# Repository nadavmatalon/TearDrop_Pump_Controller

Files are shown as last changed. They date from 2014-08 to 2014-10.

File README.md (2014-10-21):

#TearDrop Pump Controller

##Table of Contents

* [Screenshots](#screenshots)
* [About the Project](#about-the-project)
* [About the Pump Controller](#about-the-pump-controller)
* [License](#license)

##Screenshots

<table>
	<tr>
		<td align="center" width=25% >
			<a href="https://raw.githubusercontent.com/nadavmatalon/TearDrop_Pump_Controller/master/images/TDPC_Arduino.jpg">
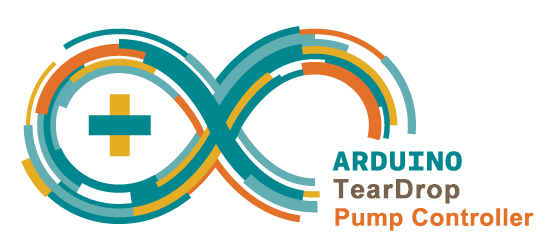
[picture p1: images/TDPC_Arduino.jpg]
				
			</a>
		</td>
		<td align="center" width=25% >
			<a href="https://raw.githubusercontent.com/nadavmatalon/TearDrop_Pump_Controller/master/images/TDPC_PCB.jpg">
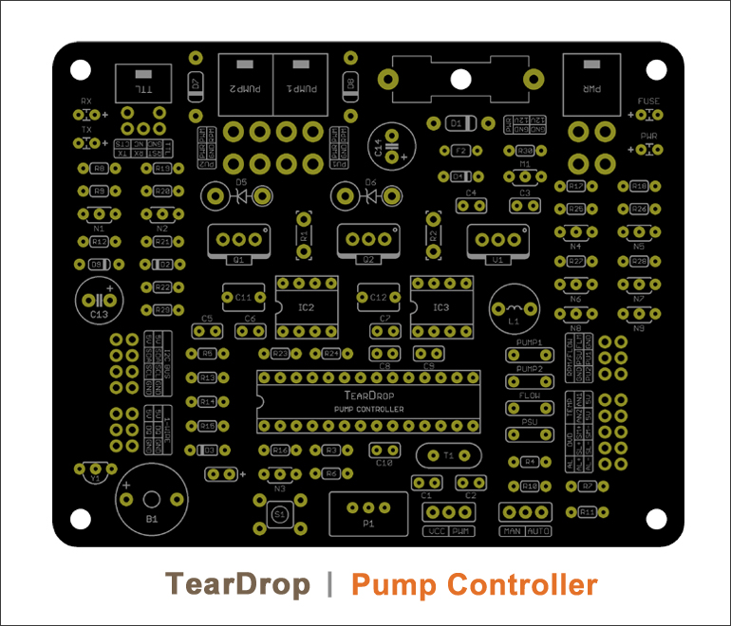
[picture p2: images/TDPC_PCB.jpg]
				
			</a>
		</td>
		<td align="center" width=25% >
			<a href="https://raw.githubusercontent.com/nadavmatalon/TearDrop_Pump_Controller/master/images/TearDrop_1.jpg">
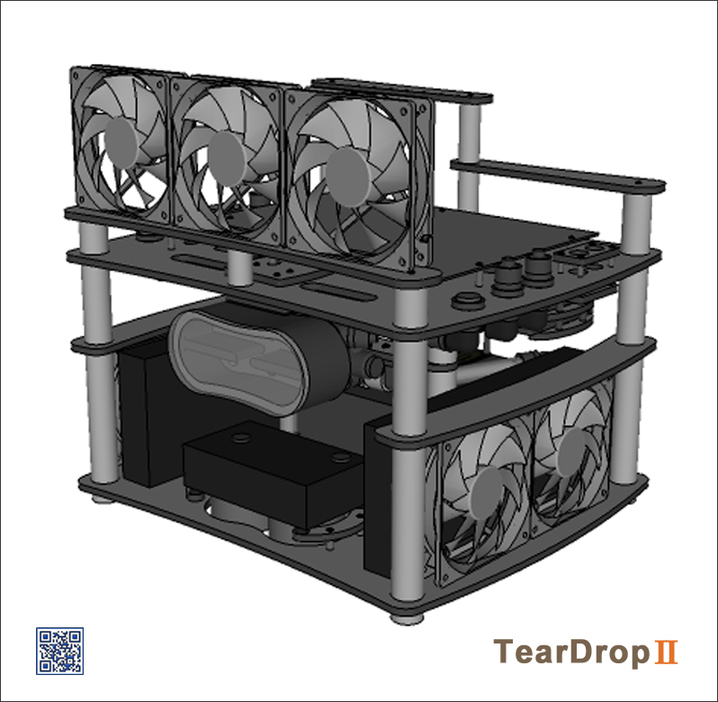
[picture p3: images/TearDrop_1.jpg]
				
			</a>
		</td>
		<td align="center" width=25% >
			<a href="https://raw.githubusercontent.com/nadavmatalon/TearDrop_Pump_Controller/master/images/TearDrop_2.jpg">
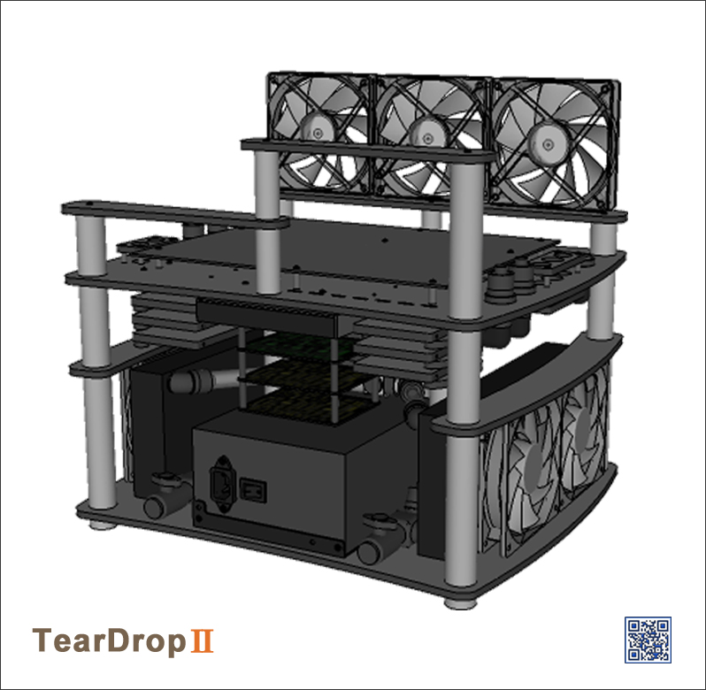
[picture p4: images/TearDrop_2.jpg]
				
			</a>
		</td>
	</tr>
</table>

##About the Project
 
__TearDrop__ is a custom, open-frame, water-cooled scratch build I’ve been 
working on as part of the SnowCrash initiative.

The __SnowCrash__ initiative aims at designing and building end-to-end customized 
personal computers, addressing unique functional requirements – from developing 
the software control applications, to hardware configuration and case modding. 
As part of the initiative's research phase, the TearDrop customized computer 
prototype has been developed.

The underlying motivation for this specifc project was to research, design, 
prototype and finally create everything that's needed for a fully-customized 
desktop computer.

In this context, I’ve learned to program micro-controllers, design, prototype 
and build electronic circuit boards, make CNC cutting templates, interface with 
various kinds of hardware, write front-end applications, and lots more.

This project also helped me to become proficient in multiple software tools, including: 
[Google Sketchup](http://www.sketchup.com/), 
[Arduino IDE](http://www.arduino.cc/), [Processing 2.0](http://processing.org/), 
[CadSoft Eagle](http://www.cadsoftusa.com/download-eagle/freeware/), 
and [Inkscape](http://www.inkscape.org/en/).
 
The __project-log__ of this build (which I haven't had time to update recently, but 
does include loads of cool pictures :-), can be found 
at [bit-tech](http://forums.bit-tech.net/showthread.php?t=234218).

##About the Pump Controller

This repo contains the custom Pump Controller I’ve designed and built 
to control __TearDrop__’s dual-pump cooling system.

This repo contains the following files:

* __arduino__

    The source code for the ATmega328P that runs the Pump Controller 

    The file can can be directly accessed by clicking this link:

    * [Pump Controller](arduino/TearDrop_Pump_Controller/TearDrop_Pump_Controller.ino)

	The source code requires three supporting open-source [Arduino](http://www.arduino.cc/) libraries.

	For convenience, these libraries are inlcuded here in their own sub-folder.

	Credit goes to:

	[PinChangeInt](http://playground.arduino.cc/Main/PinChangeInt)

	[OneWire](https://github.com/ntruchsess/arduino-OneWire/tree/master)

	[WSWire](https://github.com/steamfire/WSWireLib)

* __eagle__

    This folder contains the complete hardware schematics & PCB design of the Pump Controller.

    __Please do not click on the files in this sub-folder as they are in foramts that 
    are incompatible with Github's hosting server__.

    However, the files can be downloaded and run as usual with [CadSoft](http://www.cadsoftusa.com/?language=en)'s 
    free version of [Eagle](http://www.cadsoftusa.com/download-eagle/freeware/).

* __parts__

	A speadsheet with all information about the parts used for building the Pump Controller.

	__The file in this sub-folder is also in a foramt that's incompatible with Github's hosting server__.

    However, it can be downloaded and run as usual with any spreadsheet editing software.

##  License

<p>Released under the <a href="http://www.opensource.org/licenses/MIT">MIT license</a>.</p>

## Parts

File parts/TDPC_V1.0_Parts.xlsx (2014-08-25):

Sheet: Sheet1
TEARDROP
NAME | TYPE | VALUE / RATING | PACKAGE / DIMENSIONS | NUMBER | MANUFACTURER | MPN | SOURCE | DATASHEET | ACTUAL | ACTUAL | MINIMUM | ACTUAL | MINIMUM | MINIMUM | ACTUAL | MINIMUM | MINIMUM | MINIMUM
 |  |  | (mm) | OF |  |  |  | LEAD | LEAD | LEAD | HOLE | HOLE | ANNULAR RING | PAD | PAD | HOLE | PAD | PAD
 |  |  |  | UNITS |  |  |  | DIAMETER | DIAMETER | DIAMETER | DIAMETER | DIAMETER | SIZE | DIAMETER | DIAMETER | DIAMETER | DIAMETER | DIAMETER
 |  |  |  |  |  |  |  | (mm) | (wide side) | (narrow side) | (mm) | (mm) | (mm) | (mm) | (mm) | CHECK | CHECK (1) | CHECK (2)
PWR, PUMP1, PUMP2 | 4P (2x2) POWER SOCKET (FEMALE) | 10A | KK, HORIZONTAL | 3 | MOLEX | MB-4PIN-SB | modDIY (MB-4PIN-SB) | ─ | 1.2 | 1.2 | 1.454 | 1.75 | 0.2 | 2.25 | 3.3 | 1.35 | 0.15 | 1.0
PWR, PUMP1, PUMP2 | 4P (2x2) POWER CONNECTOR (MALE) | 10A | KK, HORIZONTAL | 3 | MOLEX | MB-4PIN-F | modDIY (MB-4PIN-F) | ─ | ─ | ─ | ─ | ─ | ─ | ─ | ─ | ─ | ─ | ─
USB-TTL | 6P (2x3) SOCKET (FEMALE) | RIGHT ANGLE, 2.54 |  | 1 | MOLEX | 90130-3206 | eBay (350819406809) |  |  |  | 0.254 |  | 0.2 | 0.5 | 1.7 | -0.4 | 1.7 | 1.2
USB-TTL | 6P (2x3) CONNECTOR (MALE) | ─ | ─ | 1 | MOLEX | 90142-0006 | eBay (111189947049) | ─ | ─ | ─ | ─ | ─ | ─ | ─ | ─ | ─ | ─ | ─
USB-TTL | CONNECTOR CRIMPS | ─ | ─ | 6 | MOLEX | 90119-2120 | eBay (111189965216) | ─ | ─ | ─ | ─ | ─ | ─ | ─ | ─ | ─ | ─ | ─
I/O | RIGHT-ANGLE MALE HEADERS | 2x3, 2x4, 2x5 | DUAL ROW, 2.54 | 3 | UNKOWN | UNKNOWN | eBay (321027689319) | ─ | 0.7 | 0.7 | 0.954 | 1.1 | 0.2 | 1.6 | 2.0 | 0.7 | 0.02 | 0.4
IC1 | ATMEGA328P | ─ | DIP-28 | 1 | ATMEL | ATMEGA328P | eBay(281158389853) | ─ | ─ | ─ | ─ | ─ | ─ | ─ | ─ | ─ | ─ | ─
(IC1) | DIL-28 SOCKET | ─ | 35.6x10, 2.54 | 1 | UNKNOWN | UNKNOWN | eBay(181062492231) | 0.5 | 0.5 | 0.5 | 0.754 | 0.7 | 0.2 | 1.2 | 1.8 | 0.3 | 0.54 | 0.6
IC2, IC3 | MIC4421 (MOFSET DRIVER) | 9A | DIP-8 | 2 | MICREL | MIC4421YN | Mouser (998-MIC4421YN) | ─ | ─ | ─ | ─ | ─ | ─ | ─ | ─ | ─ | ─ | ─
[IC2, IC3] | [MCP1406 (IMPROVEMENT OF TC4429)] | [6A] | [DIP-8] | [2] | MICROCHIP | MCP1406-E/P | Mouser (579-MCP1406-E/P) | ─ | ─ | ─ | ─ | ─ | ─ | ─ | ─ | ─ | ─ | ─
(IC2, IC3) | DIL-8 SOCKET | 3A | 10.1x10.2 | 2 | MILL-MAX | 110-44-308-41-001000 | Mouser (575-144308) | 0.5 | 0.5 | 0.5 | 0.754 | 0.7 | 0.2 | 1.2 | 1.8 | 0.3 | 0.54 | 0.6
 |  |  |  |  |  |  | Farnell (1351428)
[IC2, IC3] | [DIL-8 SOCKET] | [3A] | [10x10] | [2] | TE Connectivity / AMP | 808-AG11D-ES-LF | Mouser (571-4-1571552-3) | 0.5 | 0.5 | 0.5 | 0.754 | 0.7 | 0.2 | 1.2 | 1.8 | 0.3 | 0.54 | 0.6
Y1 | DS18B20 (DIGITAL TEMPERATURE SENSOR) | ─ | TO-92 | 1 | DALLAS | DS18B20 | eBay (301049284143) | 0.5 | 0.5 | 0.5 | 0.754 | 0.7 | 0.2 | 1.2 | 1.8 | 0.3 | 0.54 | 0.6
V1 | LM7805 (VOLTAGE REGULATOR) | 5V | TO-220 | 1 | FAIRCHILD | LM7805ACT | Mouser (512-LM7805ACT) | Narrow: 0.64 | 0.86 | 0.45 | 1.114 | 1.1 | 0.2 | 1.6 | 2.1 | 0.7 | 0.12 | 0.5
 |  |  |  |  |  |  |  | Wide: 1.52
[V1] | [LM7805 (VOLTAGE REGULATOR)] | [5V] | [TO-220] | [1] | ON SEMICONDUCTOR | MC33269T-5.0G | Mouser (863-MC33269T-5.0G) | Narrow: 0.64 | 0.86 | 0.45 | 1.114 | 1.2 | 0.2 | 1.7 | 2.1 | 0.8 | -0.06 | 0.4
 |  |  |  |  |  |  |  | Wide: 1.52
F1 | FAST-BLOW GLASS FUSE | 6.3A | 8x20MM | 1 | UKNOWN | UNKWNON | UNKNOWN | ─ | ─ | ─ | ─ | ─ | ─ | ─ | ─ | ─ | ─ | ─
(F1) | FUSE HOLDER | 10A / 250V | 22.5x9.6mm | 1 | Schurter | 0031.8211 | Mouser (693-0031.8201) | 1.3 | 1.2 | 0.46 | 1.454 | 1.45 | 0.2 | 1.95 | 3.3 | 1.05 | 0.69 | 1.3
F2 | PTC (RESETTABLE FUSE) | 0.5A / 60V | 6.8x1.9, 5.1 | 1 | BOURNS | MF-R050 | Mouser (652-MFR050) | 0.5 | 0.55 | 0.5 | 0.804 | 0.7 | 0.2 | 1.2 | 1.6 | 0.3 | 0.34 | 0.4
L1 | INDUCTOR | 10uH / 4A7 | 8.7x12.3, 5.08 | 1 | Wurth Electronics | 7447452100 | Mouser (710-7447452100) | 0.7 | 0.65 | 0.7 | 0.904 | 0.9 | 0.2 | 1.4 | 2.1 | 0.5 | 0.48 | 0.7
C1, C2 | CAPACITOR (MLCC) | 22pF / 50V | 3.8x2, 2.6 | 2 | AVX | SR155A220JAR | Mouser (581-SR155A220JAR) | 0.5 | 0.5 | 0.5 | 0.754 | 0.7 | 0.2 | 1.2 | 1.7 | 0.3 | 0.44 | 0.5
C3 | CAPACITOR (MLCC) | 470nF / 25V | 4x2.5, 3 | 1 | TDK | FK18X7R1E474K | Mouser (810-FK18X7R1E474K) | 0.5 | 0.55 | 0.55 | 0.804 | 0.7 | 0.2 | 1.2 | 1.7 | 0.3 | 0.44 | 0.5
C4 - C10 | CAPACITOR (MLCC) | 100nF / 100V | 4.3x2.9, 2.6 | 7 | NOT KNOWN | NOT KNOWN | eBay (290933035294) | 0.5 | 0.5 | 0.5 | 0.754 | 0.7 | 0.2 | 1.2 | 1.7 | 0.3 | 0.44 | 0.5
[C4 - C10] | [CAPACITOR (MLCC)] | [100nF / 25V] | [4x2.5, 3] | [7] | [TDK] | [FK18X7R1E104K] | [Mouser (810-FK18X7R1E104K)] | 0.5 | 0.5 | 0.5 | 0.754 | 0.7 | 0.2 | 1.2 | 1.8 | 0.3 | 0.54 | 0.6
C11, C12 | WIMA CAPACITOR (5%) | 2.2uF / 50V | 5x7.2, 5.2 | 2 | WIMA | MKS2B042201F00JSSD | Mouser (505-MKS22.2/50/5) | 0.5 | 0.5 | 0.5 | 0.754 | 0.7 | 0.2 | 1.2 | 1.8 | 0.3 | 0.54 | 0.6
[C11, C12] | [WIMA CAPACITOR (10%)] | [2.2uF / 50V] | [5x7.2, 5] | [2] | [WIMA] | [MKS2B042201F00KSSD] | [Mouser (505-MKS22.2/50/10 )] |  |  |  | 0.254 |  |  | 0.1 |  | -0.4 | 0 | -0.5
[C11, C12] | [WIMA CAPACITOR (10%)] | [4.7uF / 50V] | [7.2x7.2, 5] | [2] | [WIMA] | [MKS2B044701K00KSSD] | [Mouser (505-MKS2-4.7/50/10)] |  |  |  | 0.254 |  |  | 0.1 |  | -0.4 | 0 | -0.5
[C11, C12] | [WIMA CAPACITOR (5%)] | [1uF / 63V] | [5x7.2, 5] | [2] | WIMA | [MKS2C041001F00JS] | [Mouser (505-MKS21.0/63/5)] |  |  |  | 0.254 |  |  | 0.1 |  | -0.4 | 0 | -0.5
[C11, C12] | [WIMA CAPACITOR (5%)] | [1uF / 63V] | [5x7.2, 5] | [2] | [WIMA] | [MKS2-1/63/5T] | [Mouser (505-MKS21/63/5T)] |  |  |  | 0.254 |  |  | 0.1 |  | -0.4 | 0 | -0.5
C13 | CAPACITOR (ELECTROLYTIC) | 100uF / 50V | 8x12.2, 5 | 1 | PANASONIC | EEU-FR1H101B | Mouser (667-EEU-FR1H101B) | 0.6 | 0.6 | 0.6 | 0.854 | 0.9 | 0.2 | 1.4 | 2.1 | 0.5 | 0.48 | 0.7
C14 | CAPACITOR (ELECTROLITIC) | 470uF / 35V | 8.3x21.6, 3.5 | 1 | PANASONIC | EEU-FR1V471L | Mouser 667-EEU-FR1V471L | 0.6 | 0.6 | 0.6 | 0.854 | 0.9 | 0.2 | 1.4 | 2.1 | 0.5 | 0.48 | 0.7
Q1, Q2 | IRF5210 (P-CHANNEL MOSFET) | 30V / 50A | TO-220 | 2 | INTERNATIONAL RECIFIER | IRF5210PBF | Mouser (942-IRF5210PBF) | Narrow: 0.64 | 0.86 | 0.45 | 1.114 | 1.1 | 0.2 | 1.6 | 2.1 | 0.7 | 0.12 | 0.5
 |  |  |  |  |  |  |  | Wide: 1.52
(Q1, Q2, V1) | MOSFET / VOLTAGE REGULATOR HEATSINK (TO-220) | 32C/W | 6.35x13.3 | 3 | AAVID THERMALLOY | 577002B00000G | Mouser (532-577002B00) | ─ | ─ | ─ | ─ | ─ | ─ | ─ | ─ | ─ | ─ | ─
N1 - N9 | ZVN2106A (N-CHANNEL MOSFET) | 0.2A / 60V | TO-92 | 9 | FAIRCHILD | ZVN2106A | Mouser (522-ZVN2106A) | 0.5 | 0.5 | 0.5 | 0.754 | 0.7 | 0.2 | 1.2 | 1.8 | 0.3 | 0.54 | 0.6
M1 | ZVP2106A (P-CHANNEL MOSFET) | 0.2A / 60V | 2.3x4.6 | 1 | DIODES INC | ZVP2106A | Mouser (522-ZVP2106A) | 0.5 | 0.5 | 0.5 | 0.754 | 0.7 | 0.2 | 1.2 | 1.8 | 0.3 | 0.54 | 0.6
D1 | 1N4007 (POWER DIODE) | 1000V / 1A | DO-41 (5x2.6) | 1 | FAIRCHILD SEMICONDUCTOR | 1N4007 | Farnell (1467514) | 0.87 | 0.8 | 0.8 | 1.054 | 0.9 | 0.2 | 1.4 | 2.2 | 0.5 | 0.58 | 0.8
D2 - D4 | 1N4148 (SIGNAL DIODE) | 100V / 200mA | DO-35 (3.2x1.6) | 3 | FAIRCHILD SEMICONDUCTORS | 1N4148 | Mouser (512-1N4148) | 0.56 | 0.5 | 0.5 | 0.754 | 0.7 | 0.2 | 1.2 | 1.8 | 0.3 | 0.54 | 0.6
D5, D6 | ICTE12 (TVS DIODE) | 12V / 1.5KW / UD | 9x5.2 | 2 | VISHAY | ICTE12-E3/51 | Mouser (625-ICTE12-E3/51) | 1.1 | 1.1 | 1.1 | 1.354 | 1.25 | 0.2 | 1.75 | 2.6 | 0.85 | 0.35 | 0.9
D7, D8 | UF4004 (PROTECTION DIODE) | 40V / 30A | DO-41 (5x2.6) | 2 | VISHAY | UF4004-E3/54 | Mouser (625-UF4004-E3) | 0.8 | 0.8 | 0.8 | 1.054 | 0.9 | 0.2 | 1.4 | 2.2 | 0.5 | 0.58 | 0.8
D9 | BZX79-B/C5V1 (ZENER DIODE) | 5V1 / 0.5W | DO-35 (3.6x1.6) | 1 | VISHAY | BZX55B5V1-TAP | Mouser (78-BZX55B5V1-TAP) | 0.5 | 0.5 | 0.5 | 0.754 | 0.7 | 0.2 | 1.2 | 1.8 | 0.3 | 0.54 | 0.6
T1 | CRYSTAL | 16Mhz | 10.8x4.4 | 1 | ABRACON | ABL-16.000MHZ-B2 | Mouser (815-ABL-16-B2) | 0.5 | 0.45 | 0.45 | 0.704 | 0.7 | 0.2 | 1.2 | 1.8 | 0.3 | 0.54 | 0.6
P1 | POTENTIOMETER (SINGL TURN) | 10K | 12.7x7.6 | 1 | VISHAY SPECTROL | 249FGJSPXB25103KA | Farnell (9609342) | 0.5 | 0.5 | 0.4 | 0.754 | 0.7 | 0.2 | 1.2 | 1.8 | 0.3 | 0.54 | 0.6
(P1) | POTENTIOMETER KNOB | ─ | 9.4x14 (Inner: 6mm) | 1 | UNKNOWN | UNKNOWN | eBay (310496284128) | ─ | ─ | ─ | ─ | ─ | ─ | ─ | ─ | ─ | ─ | ─
R1, R2 | RESISTOR | 100R / 15W | TO-126 (8.1x2.8) | 3 | CADDOCK | MP915-100-1% | Farnell (1612032) | 0.86 | 0.8 | 0.6 | 1.054 | 1.1 | 0.2 | 1.6 | 2.3 | 0.7 | 0.32 | 0.7
 |  |  |  |  |  |  | Mouser (684-MP915-100)
R3 - R4 | RESISTOR | 470R / 0.5W | 3.15x1.6 | 2 | VISHAY | SFR16S0004700JA500 | Farnell (9476059) | 0.5 | 0.46 | 0.46 | 0.714 | 0.7 | 0.2 | 1.2 | 1.8 | 0.3 | 0.54 | 0.6
R5 - R7 | RESISTOR | 560R / 0.5W | 3.15x1.6 | 3 | VISHAY | SFR16S0005600JA500 | Farnell (9476113) | 0.5 | 0.46 | 0.46 | 0.714 | 0.7 | 0.2 | 1.2 | 1.8 | 0.3 | 0.54 | 0.6
R8 - R11 | RESISTOR | 1K / 0.5W | 3.15x1.6 | 4 | VISHAY | SFR16S0001001JA500 | Farnell (9475729) | 0.5 | 0.46 | 0.46 | 0.714 | 0.7 | 0.2 | 1.2 | 1.8 | 0.3 | 0.54 | 0.6
R12 - R18 | RESISTOR | 4K7 / 0.5W | 3.15x1.6 | 7 | VISHAY | SFR16S0004701JA500 | Farnell (9476083) | 0.5 | 0.46 | 0.46 | 0.714 | 0.7 | 0.2 | 1.2 | 1.8 | 0.3 | 0.54 | 0.6
R19 - R28 | RESISTOR | 10K / 0.5W | 3.15x1.6 | 10 | VISHAY | SFR16S0001002JA500 | Farnell (9475575) | 0.5 | 0.46 | 0.46 | 0.714 | 0.7 | 0.2 | 1.2 | 1.8 | 0.3 | 0.54 | 0.6
R29, R30 | RESISTOR | 270K / 0.5W | 3.15x1.6 | 2 | VISHAY | SFR16S0002703JA500 | Farnell (9475842) | 0.5 | 0.46 | 0.46 | 0.714 | 0.7 | 0.2 | 1.2 | 1.8 | 0.3 | 0.54 | 0.6
 | RESISTOR SOCKET | ─ | 7.5x2.75 | 4 | SURE ELECTRONICS | DC-CS11186 | eBay 370640095302 | ─ | 0.55 | 0.55 | 0.804 | 0.7 | 0.2 | 1.2 | 1.8 | 0.3 | 0.54 | 0.6
B1 | BUZZER (2.3KHz, 85dB) | 6V / 30mA | 12x9.5mm | 1 | ELECTROMECH | ABI-009-RC | eBay (271380201397) | 0.65 | 0.65 | 0.65 | 0.904 | 0.9 | 0.2 | 1.4 | 2.1 | 0.5 | 0.48 | 0.7
[B1] | [BUZZER (2.3KHz, 85dB)] | [12V / 30mA] | [11.9x8.9, 7.62] | [1] | [TMB] | [TMB12A12] | [eBay (160696996991)] | ─ | 0.6 | 0.6 | 0.854 | 0.8 | 0.2 | 1.3 | 2.1 | 0.4 | 0.66 | 0.8
PWR LED | LED (GREEN, 1.8mm) | ─ | 2.4x3.4, 2.6 | 1 | KINGBRIGHT | L-2060GD | eBay (251351814776) | 0.5 | 0.5 | 0.5 | 0.754 | 0.7 | 0.2 | 1.2 | 1.7 | 0.3 | 0.44 | 0.5
FUSE LED | LED (RED, 1.8mm) | ─ | 2.4x3.4, 2.6 | 1 | KINGBRIGHT | L-2060GD | eBay (251351814776) | 0.5 | 0.5 | 0.5 | 0.754 | 0.7 | 0.2 | 1.2 | 1.7 | 0.3 | 0.44 | 0.5
E2 | LED (RED, 5mm) | ─ | ─ | 1 | UNKNOWN | UNKNOWN | eBay (251351814776) | ─ | ─ | ─ | ─ | ─ | ─ | ─ | ─ | ─ | ─ | ─
(E2) | LED SOCKET | 2.54x2 | 5.5x2.75mm | 1 | SURE ELECTRONICS | DC-CS11186 | eBay (370640095302) | ─ | 0.55 | 0.55 | 0.804 | 0.7 | 0.2 | 1.2 | 1.8 | 0.3 | 0.54 | 0.6
E3 | LED (AMBER, 1.8mm) | ─ | 2.4x3.2, 2.54 | 1 | KINGBRIGHT | L-2060ED | eBay (251351814776) | 0.5 | 0.5 | 0.5 | 0.754 | 0.7 | 0.2 | 1.2 | 1.7 | 0.3 | 0.44 | 0.5
E4 | LED (YELLOW, 1.8mm) | ─ | 2.4x3.2, 2.54 | 1 | KINGBRIGHT | L-2060YD | eBay (251351814776) | 0.5 | 0.5 | 0.5 | 0.754 | 0.7 | 0.2 | 1.2 | 1.7 | 0.3 | 0.44 | 0.5
S1 | MOMENTARY SWITCH |  | 6x6 | 1 | UNKNOWN | UNKNOWN | UNKNOWN | ─ | 0.75 | 0.3 | 1.004 | 0.9 | 0.2 | 1.4 | 2.1 | 0.5 | 0.48 | 0.7
S2, S3 | SLIDING SWITCH | 400mA (G) / 100mA | 9x3.45 | 2 | ALCO | SSA12G | Mouser 506-SSA12G | (HOLE: 1.1) | 0.65 | 0.45 | 0.904 | 0.9 | 0.2 | 1.4 | 2.0 | 0.5 | 0.38 | 0.6
 | REFERENCES
 | CAPACITOR (ELECTROLYTIC) | 270uF / 35V | 8x15, 5 |  | PANASONIC | EEU-FR1V271LB | Mouser (667-EEU-FR1V271LB)
 | CAPACITOR (ELECTROLITIC) (ALT) | 220uF / 35V | 10x16, 5 |  | PANASONIC | EEU-FR1H221B | Mouser (667-EEU-FR1H221B)
 | 6-PIN (2x3) FEMALE SOCKET (USB-TTL) | Horizontal, female | 2mm |  | HIROSE | DF11-6DP-2DS(52) | Mouser (798-DF11-6DP-2DS52)
 | 6-PIN (3x2) MALE HEADER (USB-TTL) | Male, 2mm |  |  | HIROSE | DF11-6DS-2C(20) | Mouser (798-DF11-6DS-2C20)
 | 6-PIN (2x3) MALE CRIMPS | CRIMPS |  |  | HIROSE | DF11-2428SCA | Mouser (798-DF11-2428SCA)
 | WIMA CAPACITOR (5%) | 4.7uF/63V | 18x7, 15 |  | WIMA | MKS4C044704D00JSSD | Mouser (505-MKS44.7/63/5) |  |  |  | 0.254 |  |  | 0.1 |  | -0.4 | 0 | -0.5
 | ULN2003A (7 DARLINGTON ARRAY) | ─ | 16 DIP | 1 | STMELECTRONICS | ULN2003A | Mouser 511-ULN2003A | ─ | ─ | ─ | ─ | ─ | ─ | ─ | ─ | ─ | ─ | ─
 | DIP-16 SOCKET | 1A | 10x20.4 | 1 | UNKNOWN | UNKNOWN | eBay 180727655109 | 0.5 | 0.54 | 0.54 | 0.794 | 0.7 | 0.2 | 1.2 | 1.8 | 0.3 | 0.54 | 0.6
 | 4-PIN FAN HEADER (FEMALE) | ─ | HORIZONTAL (2.54mm) | 2 | MOLEX | FC-4P-M | modDIY FC-4P-M | ─ | 0.7 | 0.7 | 0.954 | 1.1 | 0.2 | 1.6 | 2.1 | 0.7 | 0.12 | 0.5
 | 2N7000 (N-CHANNEL MOSFET) | 0.2A / 60V | TO-92 | 9 | FAIRCHILD | 2N7000TA | Mouser (512-2N7000TA) |  |  |  | 0.254 |  |  | 0.1 |  | -0.4 | 0 | -0.5
USB-TTL | 6P (2x3) SOCKET (FEMALE) | VERTICAL, 2.54 |  | 1 | MOLEX | 90130-1206 | eBay (121194705280) |  |  |  | 0.254 |  | 0.2 | 0.5 | 1.7 | -0.4 | 1.7 | 1.2
I2C | 4P SOCKET (1X4) (FEMALE SHROUDED) | VERTICAL, 2.54 | 5x12.7, 2.54 | 1 | TE CONNECTIVITY | 280371-2 | eBay (121194685732)
I2C | 4P CONNECTOR (1X4) (MALE) | ─ | ─ | 1 | TE CONNECTIVITY | 280359 | eBay (131082753469)
I2C | 4P CONNECTOR (1X4) PINS | ─ | ─ | 10 | TE CONNECTIVITY | 170204-1 | eBay (121194671373)
I2C | 4P HEADER (1X4) (FEMALE) | VERTICAL, 2.54 |  | 1 |  | ─ | eBay (301087252736)
 |  |  |  |  |  |  | ebay (150964856124)
 |  |  |  |  |  |  | Farnell (2352003)

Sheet: Sheet2
ACTUAL | NUMBER | NUMBER | ACTUAL
HOLE | OF | OF | PAD
DIAMETER | HOLES | HOLES | DIAMETER
(mm) | CATEGORY | TOTAL | (mm)
0.8 | 12 | 91 | 1.6
0.9 | 4 | 38 | 2
1.1 | 4 | 46 | 2.1
1.2 | 2 | 15 | 2.0/2.3
1.75 | 3 | 12 | 3.3/3.4
3.2 | 1 | 4 | ─
 | TOTAL | 206

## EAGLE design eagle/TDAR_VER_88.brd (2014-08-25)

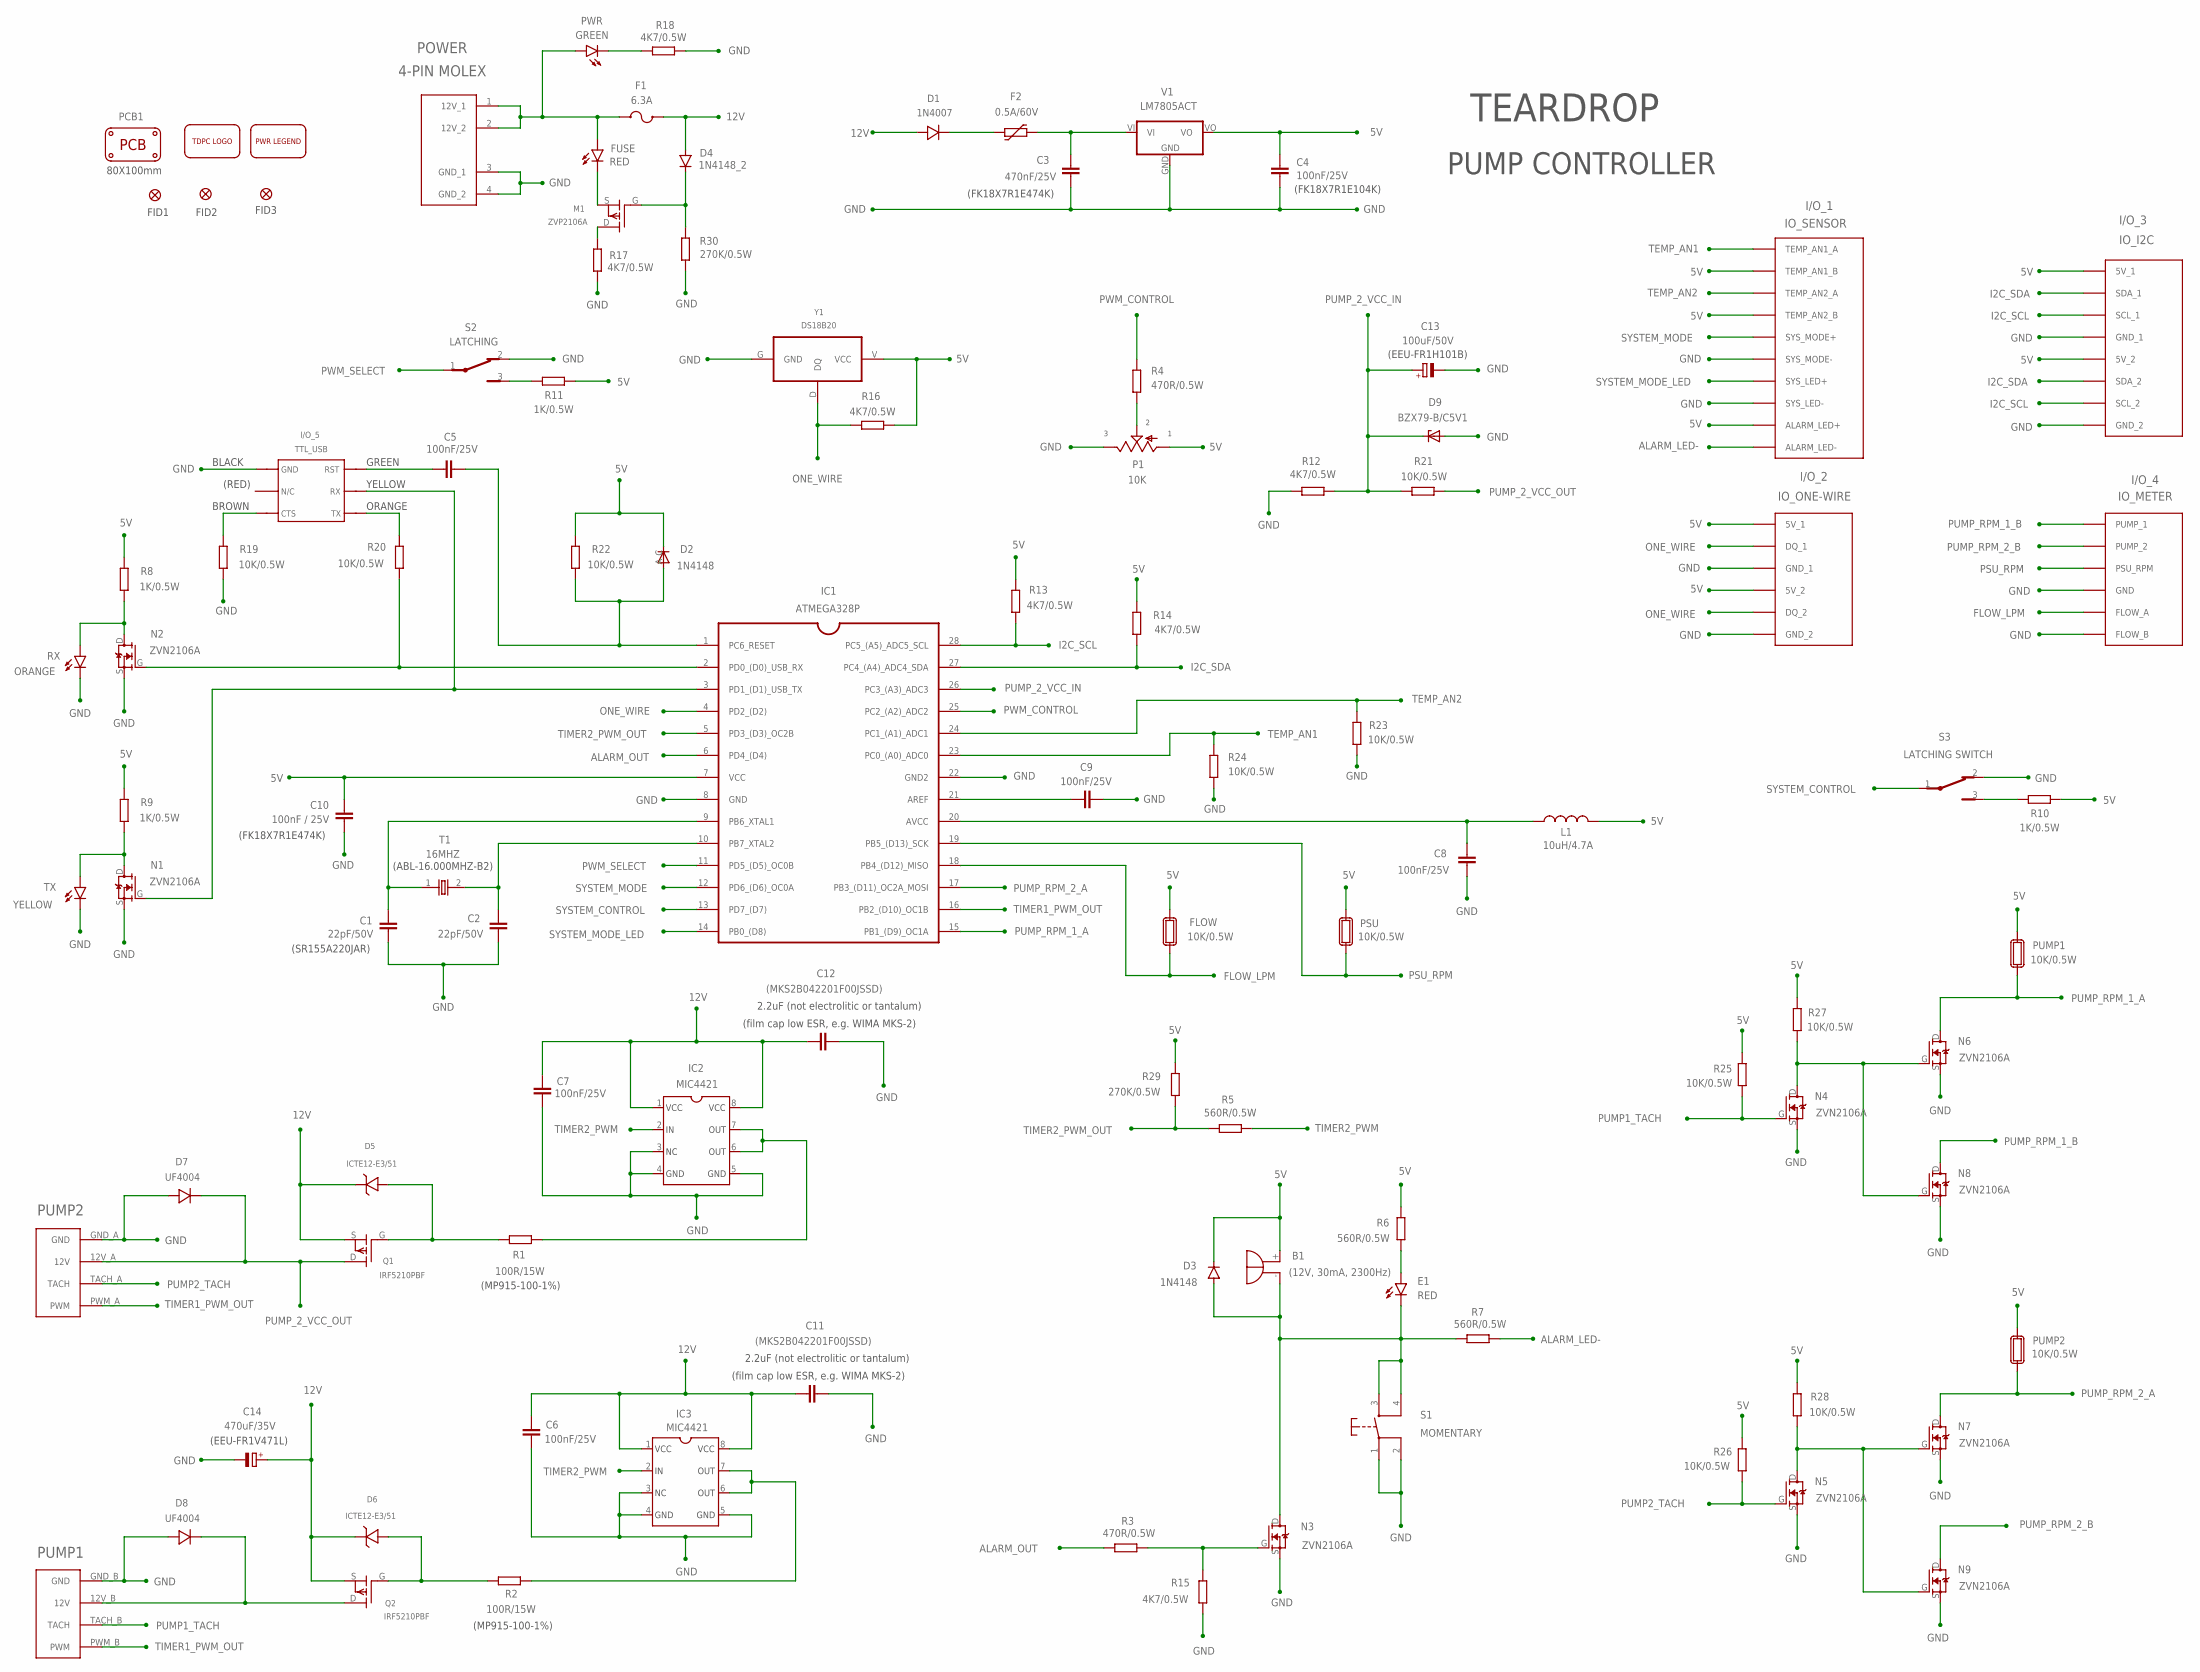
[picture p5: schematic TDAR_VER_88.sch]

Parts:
B1: (12V, 30mA, 2300Hz); F/TMB
C1: 22pF/50V; MLCC_CERAMIC_12
C2: 22pF/50V; MLCC_CERAMIC_11
C3: 470nF/25V; MLCC_CERAMIC_8
C4, C5, C6, C7: 100nF/25V; MLCC_CERAMIC
C8, C9: 100nF/25V; MLCC_CERAMIC_7
C10: 100nF / 25V; MLCC_CERAMIC_6
C11, C12: (MKS2B042201F00JSSD); WIMA_CAPACITOR
C13: 100uF/50V; E5-10,5
C14: 470uF/35V; E5-10,5
D1: 1N4007; UF4004
D2: 1N4148; DO35-7
D3: 1N4148
D4: 1N4148_2
D5, D6: ICTE12-E3/51; TVS_DIODE
D7, D8: UF4004; UF4004_2
D9: BZX79-B/C5V1; DO34Z7
E1: RED; LED_5_HORIZONTAL
F1: 6.3A; FUSE_GLASS
F2: 0.5A/60V; PTC
FID1, FID2, FID3: FIDUCIAL1X2; FIDUCIAL-1X2
FLOW: 10K/0.5W; RESISTOR_SOCKET_TOP
FUSE: RED; LED_1.8_LEFT
I/O_1: IO_SENSOR; IO_GENERAL_4
I/O_2: IO_ONE-WIRE; I0_ONE-WIRE
I/O_3: IO_I2C
I/O_4: IO_METER; IO_SENSOR_4
I/O_5: TTL_USB; TTL_USB_7
IC1: ATMEGA328P
IC2, IC3: MIC4421; TC4420
L1: 10uH/4.7A; IRF24
M1: ZVP2106A
N1, N2, N3, N4, N5, N6, N7, N8, N9: ZVN2106A
P1: 10K; POTENTIMETER_SQUARE
PCB1: 80X100mm; DP10080_V1
POWER: 4-PIN MOLEX; MOLEX_4PIN_2
PSU: 10K/0.5W; RESISTOR_SOCKET_TOP
PUMP1, PUMP2: 10K/0.5W; RESISTOR_SOCKET_TOP
PUMP_2: PUMP2; MOLEX_POWER_8_PIN_HORIZONTAL_2
PWR: GREEN; LED_1.8_LEFT
Q1, Q2: IRF5210PBF; IRF5210
R1, R2: 100R/15W; V234/12
R3, R4: 470R/0.5W; 0204/5
R5, R6, R7: 560R/0.5W; 0204/5
R8, R9, R10, R11: 1K/0.5W; 0204/5
R12, R13, R14, R15, R16, R17, R18: 4K7/0.5W; 0204/5
R19, R20, R21, R22, R23, R24, R25, R26, R27, R28: 10K/0.5W; 0204/5
R29, R30: 270K/0.5W; 0204/5
RX: ORANGE; LED_1.8_RIGHT
S1: MOMENTARY; MOM_SWITCH_6.0
S2: LATCHING; SLIDING_SWITCH_5
S3: LATCHING SWITCH; SLIDING_SWITCH_4
T1: 16MHZ; CRYSTAL_16MHZ
TX: YELLOW; LED_1.8_RIGHT
U$1: TDPC_LOGO
U$2: MOLEX_4PIN_LEGEND
V1: LM7805ACT; LM7805
Y1: DS18B20

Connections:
5V: B1.+, C4.2, C10.1, D2.C, D3.C, FLOW.1, I/O_1.5V_1 (TEMP_AN1_B), I/O_1.5V_2 (TEMP_AN2_B), I/O_1.ALARM_LED+, I/O_2.5V_1, I/O_2.5V_2, I/O_3.5V_1, I/O_3.5V_2, IC1.7 (VCC), L1.2, P1.1 (A), PSU.1, PUMP1.1, PUMP2.1, R6.1, R8.1, R9.1, R10.2, R11.2, R13.2, R14.1, R16.2, R22.1, R25.1, R26.1, R27.1, R28.2, R29.1, V1.VO, Y1.V (VCC)
12V: C6.2, C7.2, C11.1, C12.1, C14.+, D1.A, D4.A, D5.C, D6.C, F1.2, IC2.1, IC2.8, IC3.1, IC3.8, Q1.S, Q2.S
ALARM_LED-: I/O_1.ALARM_LED-, R7.2
ALARM_OUT: IC1.6 (PD4_(D4)), R3.2
CRYSTAL_A: C1.1, IC1.9 (PB6_XTAL1), T1.1
CRYSTAL_B: C2.1, IC1.10 (PB7_XTAL2), T1.2
D4: D5.A, Q1.G, R1.1
FLOW_LPM: FLOW.2, I/O_4.FLOW_A, IC1.18 (PB4_(D12)_MISO)
GND: C1.2, C2.2, C3.2, C4.1, C6.1, C7.1, C8.2, C9.2, C10.2, C11.2, C12.2, C13.-, C14.-, D7.A, D8.A, D9.A, I/O_1.SYSTEM_LED- (SYS_LED-), I/O_1.SYSTEM_MODE- (SYS_MODE-), I/O_2.GND_1, I/O_2.GND_2, I/O_3.GND_1, I/O_3.GND_2, I/O_4.FLOW_B, I/O_4.GND, I/O_5.GND, IC1.8 (GND), IC1.22 (GND2), IC2.3, IC2.4, IC2.5, IC3.3, IC3.4, IC3.5, N1.S, N2.S, N3.S, N4.S, N5.S, N6.S, N7.S, N8.S, N9.S, P1.3 (E), POWER.3 (GND_1), POWER.4 (GND_2), PUMP_2.GND_A (GND), PUMP_2.GND_B (GND), R12.1, R15.1, R17.2, R18.1, R19.2, R23.1, R24.2, R30.2, RX.K (C), S1.1, S1.2, S2.2, S3.2, TX.K (C), V1.GND, Y1.G (GND)
I2C_SCL: I/O_3.SCL_1, I/O_3.SCL_2, IC1.28 (PC5_(A5)_ADC5_SCL), R13.1
I2C_SDA: I/O_3.SDA_1, I/O_3.SDA_2, IC1.27 (PC4_(A4)_ADC4_SDA), R14.2
unnamed: R11.1, S2.3
unnamed: D4.C, M1.G, R30.1
unnamed: C8.1, IC1.20 (AVCC), L1.1
unnamed: PWR.K (C), R18.2
unnamed: P1.2 (S), R4.1
unnamed: IC2.6, IC2.7, R1.2
unnamed: D6.A, Q2.G, R2.1
unnamed: IC3.6, IC3.7, R2.2
unnamed: FUSE.K (C), M1.S
unnamed: N4.D, N6.G, N8.G, R27.2
unnamed: C9.1, IC1.21 (AREF)
unnamed: N3.G, R3.1, R15.2
unnamed: R10.1, S3.3
unnamed: D1.C, F2.1
unnamed: N1.D, R9.2, TX.A
unnamed: N2.D, R8.2, RX.A
unnamed: M1.D, R17.1
unnamed: E1.A, R6.2
unnamed: N5.D, N7.G, N9.G, R28.1
unnamed: B1.-, D3.A, E1.K (C), N3.D, R7.1, S1.3, S1.4
ONE_WIRE: I/O_2.DQ_1, I/O_2.DQ_2, IC1.4 (PD2_(D2)), R16.1, Y1.D (DQ)
POST_FUSE: C3.1, F2.2, V1.VI
PSU_RPM: I/O_4.PSU (PSU_RPM), IC1.19 (PB5_(D13)_SCK), PSU.2
PUMP1_TACH: N4.G, PUMP_2.TACH_B (TACH), R25.2
PUMP2_TACH: N5.G, PUMP_2.TACH_A (TACH), R26.2
PUMP_1_VCC_OUT: D8.C, PUMP_2.12V_B (12V), Q2.D
PUMP_2_VCC_IN: C13.+, D9.C, IC1.26 (PC3_(A3)_ADC3), R12.2, R21.1
PUMP_2_VCC_OUT: D7.C, PUMP_2.12V_A (12V), Q1.D, R21.2
PUMP_RPM_1_A: IC1.15 (PB1_(D9)_OC1A), N6.D, PUMP1.2
PUMP_RPM_1_B: I/O_4.PUMP_1, N8.D
PUMP_RPM_2_A: IC1.17 (PB3_(D11)_OC2A_MOSI), N7.D, PUMP2.2
PUMP_RPM_2_B: I/O_4.PUMP_2, N9.D
PWM_CONTROL: IC1.25 (PC2_(A2)_ADC2), R4.2
PWM_SELECT: IC1.11 (PD5_(D5)_OC0B), S2.1
PWR_IN: F1.1, FUSE.A, POWER.1 (12V_1), POWER.2 (12V_2), PWR.A
RESET: C5.1, D2.A, IC1.1 (PC6_RESET), R22.2
SYSTEM_CONTROL: IC1.13 (PD7_(D7)), S3.1
SYSTEM_MODE: I/O_1.SYSTEM_MODE+ (SYS_MODE+), IC1.12 (PD6_(D6)_OC0A)
SYSTEM_MODE_LED: I/O_1.SYSTEM_LED+ (SYS_LED+), IC1.14 (PB0_(D8))
TEMP_AN1: I/O_1.TEMP_AN1 (TEMP_AN1_A), IC1.23 (PC0_(A0)_ADC0), R24.1
TEMP_AN2: I/O_1.TEMP_AN2 (TEMP_AN2_A), IC1.24 (PC1_(A1)_ADC1), R23.2
TIMER1_PWM_OUT: IC1.16 (PB2_(D10)_OC1B), PUMP_2.PWM_A (PWM), PUMP_2.PWM_B (PWM)
TIMER2_PWM: IC2.2, IC3.2, R5.2
TIMER2_PWM_OUT: IC1.5 (PD3_(D3)_OC2B), R5.1, R29.2
USB_CTS: I/O_5.CTS, R19.1
USB_RESET_2: C5.2, I/O_5.RST
USB_RX: IC1.2 (PD0_(D0)_USB_RX), N2.G, R20.2
USB_RX_2: I/O_5.TX, R20.1
USB_TX: I/O_5.RX, IC1.3 (PD1_(D1)_USB_TX), N1.G

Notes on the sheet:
FID1
FID2
FID3
(film cap low ESR, e.g. WIMA MKS-2)
TEARDROP
GREEN
YELLOW
ORANGE
BROWN
BLACK
(RED)
2.2uF (not electrolitic or tantalum)
(FK18X7R1E104K)
(FK18X7R1E474K)
(SR155A220JAR)
(EEU-FR1V471L)
(EEU-FR1H101B)
(MP915-100-1%)
PUMP1
PUMP CONTROLLER
(ABL-16.000MHZ-B2)

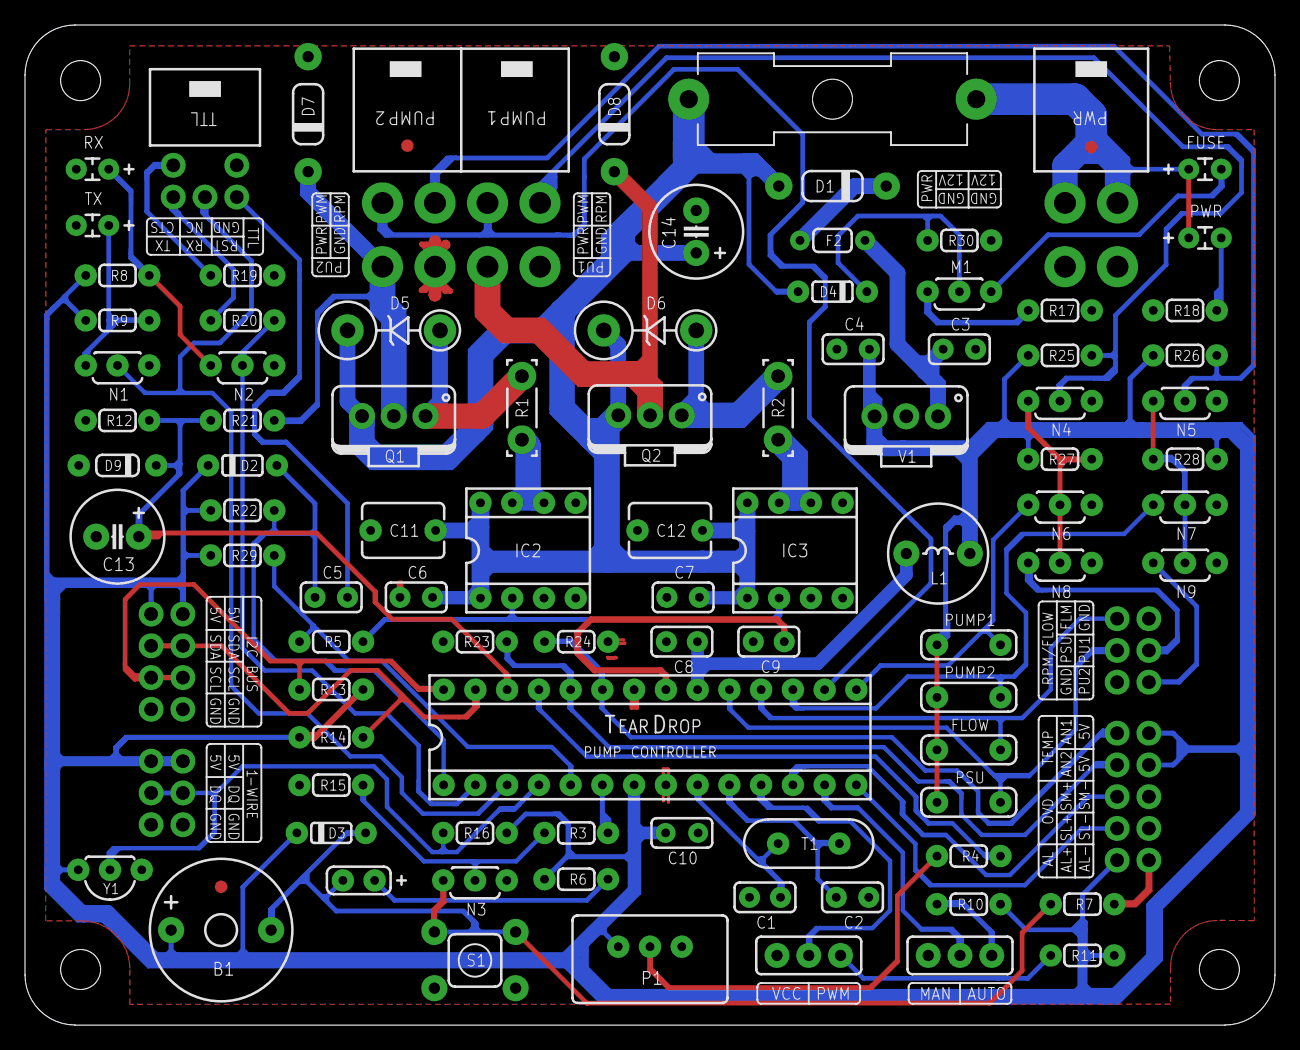
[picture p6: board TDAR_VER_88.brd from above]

Board: 2 copper layers, 100.0 x 80.0 mm, 101 parts (0 on the bottom side), 60 nets.

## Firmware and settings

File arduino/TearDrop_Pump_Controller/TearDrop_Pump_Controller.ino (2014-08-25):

// TearDrop
// Pump Controller
// Version 99.0 
// ATmega328P
// Created by Nadav Matalon
// 24 August 2014

// (TDCR_IC_PUMP_99)


// PUMP CONTROLLER (COM5)

// PIN_D2  (PIN 4)   -  ONE_WIRE
// PIN_D3  (PIN 5)   -  FREQ_VCC (TIMER2)
// PIN_D4  (PIN 6)   -  ALARM_OUT
// PIN_D5  (PIN 11)  -  SYSTEM_MODE (VCC/PWM)
// PIN_D6  (PIN 12)  -  SYSTEM_CONTROL_1 (OVD_OFF/OVD_ON)
// PIN_D7  (PIN 13)  -  SYSTEM_CONTROL_2 (MAN/AUTO)
// PIN_D8  (PIN 14)  -  SYSTEM_CONTROL_LED
// PIN_D9  (PIN 15)  -  PUMP_RPM_1
// PIN_D10 (PIN 16)  -  FREQ_PWM (TIMER1)
// PIN_D11 (PIN 17)  -  PUMP_RPM_2
// PIN_D12 (PIN 18)  -  PUMP_FLOW
// PIN_D13 (PIN 19)  -  PSU_RPM
// PIN_A0  (PIN 23)  -  TEMP_AN1
// PIN_A1  (PIN 24)  -  TEMP_AN2
// PIN_A2  (PIN 25)  -  PUMP_CONTROL (RAW_POT)
// PIN_A3  (PIN 26)  -  PUMP_VCC
// PIN_A4  (PIN 27)  -  I2C_SDA
// PIN_A5  (PIN 28)  -  I2C_SCL

// http://playground.arduino.cc/Main/PinChangeInt
// http://code.google.com/p/arduino-pinchangeint/
#include <PinChangeInt.h>

// http://playground.arduino.cc/Learning/OneWire
// https://github.com/ntruchsess/arduino-OneWire/tree/master
#include <OneWire.h>

// https://github.com/steamfire/WSWireLib
#include <WSWire.h>



const boolean DEBUG_MODE = false;		// DEBUG_MODE
// const boolean DEBUG_MODE = true;		// DEBUG_MODE

// const boolean PRINT_FIRST_ROW = false;	// DEBUG_MODE
const boolean PRINT_FIRST_ROW = true;		// DEBUG_MODE

// const boolean PRINT_SECOND_ROW = false;	// DEBUG_MODE
const boolean PRINT_SECOND_ROW = true;		// DEBUG_MODE

const boolean PSU_ALARM = false;		// PSU_ALARM_OFF
// const boolean PSU_ALARM = true;		// PSU_ALARM_ON


const byte PIN_D2 = 2;				// ONE_WIRE
const byte PIN_D3 = 3;				// FREQ_VCC (TIMER2)
const byte PIN_D4 = 4;				// ALARM_OUT
const byte PIN_D5 = 5;				// SYSTEM_MODE (VCC/PWM)
const byte PIN_D6 = 6;				// SYSTEM_CONTROL_1 (OVD_ON/OVD_OFF)
const byte PIN_D7 = 7;				// SYSTEM_CONTROL_2 (MAN/AUTO)
const byte PIN_D8 = 8;				// SYSTEM_CONTROL_LED
const byte PIN_D9 = 9;				// PUMP_RPM_1
const byte PIN_D10 = 10;			// FREQ_PWM (TIMER1)
const byte PIN_D11 = 11;			// PUMP_RPM_2
const byte PIN_D12 = 12;			// FLOW_LPM
const byte PIN_D13 = 13;			// PSU_RPM
const byte PIN_A0 = A0;				// TEMP_AN1
const byte PIN_A1 = A1;				// TEMP_AN2
const byte PIN_A2 = A2;				// PUMP_CONTROL (RAW_POT)
const byte PIN_A3 = A3;				// PUMP_VCC

const byte ADC_A0 = 0;									// ADC input channel PIN_A0
const byte ADC_A1 = 1;									// ADC input channel PIN_A1
const byte ADC_A2 = 2;									// ADC input channel PIN_A2
const byte ADC_A3 = 3;									// ADC input channel PIN_A3
const byte ADC_A4 = 4;									// ADC input channel PIN_A4
const byte ADC_A5 = 5;									// ADC input channel PIN_A5
const byte ADC_TEMP = 8;								// ADC input channel IC_TEMP
const byte ADC_VCC = 14;								// ADC input channel IC_VCC
const byte ADC_GND = 15;								// ADC input channel IC_GND

const unsigned int RPM_THRESHOLD = 500;							// defines Alarm activation lower threshold for RPM counters (in RPM)
const unsigned int FLOW_THRESHOLD = 400;			        		// defines Alarm activation lower threshold for FLOW Sensor (in LPM)
const unsigned int AN_TEMP_THRESHOLD = 500;						// defines Alarm activation higher threshold for Analog Temp sensors (in Celsuis)
const unsigned int IC_TEMP_THRESHOLD = 500;						// defines Alarm activation higher threshold for IC (ATmega328p) Internal sensor (in Celsuis)

const float TEMP_OFFSET_A0 = 1.00;							// TEMP_AN1 - calibration function: higher OFFSET precentage => lower temperature readings
const float TEMP_OFFSET_A1 = 1.00;							// TEMP_AN2 - calibration function: higher OFFSET precentage => lower temperature readings

const unsigned int TEMP_RESISTOR_A0 = 10000;	// TEMP_AN1_RESISTOR			// TEMP_AN1 - resistor value on PIN_A0 (in Ohms)
const unsigned int TEMP_RESISTOR_A1 = 10000;	// TEMP_AN2_RESISTOR			// TEMP_AN2 - resistor value on PIN_A1 (in Ohms)

const unsigned int FLOW_DIAMETER_OFFSET = 307;						// set for 10mm tube diameter 

OneWire wireBus(PIN_D2);  						        	// sets up One-Wire bus on PIN_D2

const unsigned int PC_SYSTEM_STATUS = 1001;	// SYSTEM_STATUS (OK/ALARM) 		// PC_SYSTEM_STATUS processing update command
const unsigned int PC_SYSTEM_CONTROL_1 = 1002;	// SYSTEM_CONTROL_1(OVD_OFF/OVD_ON)	// PC_SYSTEM_CONTROL_1 processing update command
const unsigned int PC_SYSTEM_CONTROL_2 = 1003;	// SYSTEM_CONTROL_2(MAN/AUTO)		// PC_SYSTEM_CONTROL_2 processing update command
const unsigned int PC_VCC_PUMP = 1004;		// VCC_PUMP				// PC_VCC_PUM processing update command
const unsigned int PC_VCC_ICP = 1005;		// VCC_ICP				// PC_VCC_ICP processing update command
const unsigned int PC_SYSTEM_MODE = 1006;	// SYSTEM_MODE (VCC/PWM)		// PC_SYSTEM_MODE processing update command
const unsigned int PC_PUMP_RPM_1 = 1007;	// PUMP_RPM_1				// PC_PUMP_RPM_1 processing update command
const unsigned int PC_PUMP_RPM_2 = 1008;	// PUMP_RPM_2				// PC_PUMP_RPM_2 processing update command
const unsigned int PC_PSU_RPM = 1009;		// PSU_RPM				// PC_PSU_RPM processing update command
const unsigned int PC_PUMP_FLOW = 1010;		// PUMP_FLOW				// PC_PUMP_FLOW processing update command
const unsigned int PC_DUTY_CYCLE_PER = 1011;	// PUMP_DUTY_CYCLE_PER			// PC_DUTY_CYCLE_PER processing update command
const unsigned int PC_TEMP_AN1 = 1012;		// TEMP_AN1				// PC_TEMP_AN1 processing update command
const unsigned int PC_TEMP_AN2 = 1013;		// TEMP_AN2 				// PC_TEMP_AN2 processing update command
const unsigned int PC_TEMP_DGP = 1014;		// TEMP_DGP (TEMP_OW_1)			// PC_TEMP_DGP processing update command
const unsigned int PC_TEMP_ICP = 1015;		// TEMP_ICP 				// PC_TEMP_ICP processing update command
const unsigned int PC_FREQ_VCC = 1016;		// FREQ_VCC				// PC_FREQ_VCC processing update command
const unsigned int PC_FREQ_PWM = 1017;		// FREQ_PWM				// PC_FREQ_PWM processing update command
const unsigned int PC_RAM_ICP = 1018;		// RAM_ICP 				// PC_RAM_ICP processing update command

const unsigned int PC_TEMP_OW_1 = 1019;		// TEMP_OW_2				// PC_TEMP_OW_1 processing update command
const unsigned int PC_TEMP_OW_2 = 1020;		// TEMP_OW_3				// PC_TEMP_OW_2 processing update command

const unsigned int PC_TEMP_I2C_1 = 1021;	// TEMP_I2C_1				// PC_TEMP_I2C_1 processing update command
const unsigned int PC_TEMP_I2C_2 = 1022;	// TEMP_I2C_2				// PC_TEMP_I2C_2 processing update command

const unsigned int FC_SYSTEM_CONTROL_1 = 2001;	// SYSTEM_CONTROL_1 (OVD_OFF/OVD_ON)	// FC_SYSTEM_CONTROL_1 processing update command
const unsigned int FC_SYSTEM_CONTROL_2 = 2002;	// SYSTEM_CONTROL_2 (MAN/AUTO)		// FC_SYSTEM_CONTROL_2 processing update command
const unsigned int FC_FAN_VCC_1 = 2003;		// FAN_VCC_1				// FC_FAN_VCC_1 processing update command
const unsigned int FC_FAN_VCC_2 = 2004;		// FAN_VCC_2				// FC_FAN_VCC_2 processing update command
const unsigned int FC_VCC_ICF = 2005;		// VCC_ICF (BOTTOM)			// FC_VCC_IC processing update command
const unsigned int FC_FAN_MODE_1 = 2006;	// FAN_MODE_1 (VCC_1/PWM_1)		// FC_FAN_MODE_1 processing update command
const unsigned int FC_FAN_RPM_1 = 2007;		// FAN_RPM_1				// FC_FAN_RPM_1 processing update command
const unsigned int FC_FAN_RPM_2 = 2008;		// FAN_RPM_2				// FC_FAN_RPM_2 processing update command
const unsigned int FC_FAN_RPM_3 = 2009;		// FAN_RPM_3				// FC_FAN_RPM_3 processing update command
const unsigned int FC_FAN_RPM_4 = 2010;		// FAN_RPM_4				// FC_FAN_RPM_4 processing update command
const unsigned int FC_DUTY_CYCLE_PER_1 = 2011;	// DUTY_CYCLE_PER_1			// FC_DUTY_CYCLE_PER_1 processing update command
const unsigned int FC_FAN_MODE_2 = 2012;	// FAN_MODE_2 (VCC_2/PWM_2)		// FC_FAN_MODE_2 processing update command
const unsigned int FC_FAN_RPM_5 = 2013;		// FAN_RPM_5				// FC_FAN_RPM_5 processing update command
const unsigned int FC_FAN_RPM_6 = 2014;		// FAN_RPM_6				// FC_FAN_RPM_6 processing update command
const unsigned int FC_DUTY_CYCLE_PER_2 = 2015;	// DUTY_CYCLE_PER_2			// FC_DUTY_CYCLE_PER_2 processing update command
const unsigned int FC_TEMP_AN1 = 2016;		// TEMP_AN1				// FC_TEMP_AN3 processing update command
const unsigned int FC_TEMP_AN2 = 2017;		// TEMP_AN2				// FC_TEMP_AN4 processing update command
const unsigned int FC_TEMP_DGF = 2018;		// TEMP_DGF (TEMP_OW_1)			// FC_TEMP_DG processing update command
const unsigned int FC_TEMP_ICF = 2019;		// TEMP_ICF (TOP)			// FC_TEMP_IC processing update command
const unsigned int FC_FREQ_VCC_1 = 2020;	// FREQ_VCC_1				// FC_FREQ_VCC_1 processing update command
const unsigned int FC_FREQ_PWM_1 = 2021;	// FREQ_PWM_1				// FC_FREQ_PWM_1 processing update command
const unsigned int FC_FREQ_VCC_2 = 2022;	// FREQ_VCC_2				// FC_FREQ_VCC_2 processing update command
const unsigned int FC_FREQ_PWM_2 = 2023;	// FREQ_PWM_2				// FC_FREQ_PWM_2 processing update command
const unsigned int FC_RAM_ICF = 2024;		// RAM_ICF (BOTTOM)			// FC_RAM_ICF processing update command

const unsigned int FC_TEMP_OW_3 = 2025;		// TEMP_OW_3				// FC_TEMP_OW_3 processing update command
const unsigned int FC_TEMP_OW_4 = 2026;		// TEMP_OW_4				// FC_TEMP_OW_4 processing update command

const unsigned int FC_TEMP_I2C_3 = 2027;	// TEMP_I2C_3				// FC_TEMP_I2C_3 processing update command
const unsigned int FC_TEMP_I2C_4 = 2028;	// TEMP_I2C_4				// FC_TEMP_I2C_4 processing update command

const unsigned int FC_PLACE_HOLDER = 2029;	// FC_PLACE_HOLDER			// FC_PLACE_HOLDER processing update command


// const byte M2_ADDRESS = 40;			// FAN_CONTROLLER_IC2			// M2 I2C device address

const byte M1_ADDRESS = 50;			// FAN_CONTROLLER_IC1			// M1 I2C device address

const byte PC_ADDRESS = 60;			// PC_I2C_ADDRESS			// PC I2C device address

const byte PC_PING = 100;

const byte PC_DATA_IN_COUNT = 30;

const byte PC_PACKAGE_1 = 245;
const byte PC_PACKAGE_2 = 246;
const byte PC_PACKAGE_3 = 247;
const byte PC_PACKAGE_4 = 248;

const byte MAX_OW_DEVICES = 3;           						// determines maximum number of One-Wire devices on bus
const byte OW_DEVICE_1 = 0;								// One-Wire device 1 location in device address arrey
const byte OW_DEVICE_2 = 1;								// One-Wire device 2 location in device address arrey
const byte OW_DEVICE_3 = 2;								// One-Wire device 3 location in device address arrey

const byte MAX_I2C_TEMP_DEVICES = 2;             					// sets maximum number of digital temperature sensors on I2C bus
const byte I2C_DEVICE_1 = 0;								// I2C_device_1 location in I2C_address arrey
const byte I2C_DEVICE_2 = 1;								// I2C_device_2 location in I2C_address arrey

volatile boolean got_data = false;
volatile byte data_in[PC_DATA_IN_COUNT] = {0};

volatile unsigned long currentBurp_D9 = 0;						// stores rpm count for ISR on PIN_D9
volatile unsigned long currentBurp_D11 = 0;						// stores rpm count for ISR on PIN_D11
volatile unsigned long currentBurp_D12 = 0;						// stores rpm count for ISR routine on PIN_D12
volatile unsigned long currentBurp_D13 = 0;						// stores rpm count for ISR on PIN_D13

volatile unsigned long ovf1 = 0;		// TIMER1_OVERFLOW			// stores TIMER1 overflow count
volatile unsigned long ovf2 = 0;		// TIMER2_OVERFLOW			// stores TIMER2 overflow count

volatile unsigned int current_duty_cycle;						// stores current duty_cycle value of FAN_CHANNEL_1

unsigned int freq_VCC = 0;			// FREQ_VCC				// stores freq_VCC (TIMER2) frequency reading
unsigned int freq_PWM = 0;			// FREQ_PWM				// stores freq_PWM (TIMER1) frequency reading

unsigned int ocr1b_data = 638;
unsigned int ocr2b_data = 78;

boolean system_status = false;			// SYSTEM_STATUS (OK/ALARM)		// SYSTEM_STATUS (0 => OK / 1 => ALARM)

boolean system_control_1 = true;		// OVD_OFF/OVD_ON			// stores state of swtich on PIN_D6 (OVD_ON/OVD_OFF)

boolean system_control_2 = true;		// MAN/AUTO				// stores state of swtich on PIN_D7 (MAN/AUTO)

boolean system_mode = true;			// VCC/PWM				// stores state of swtich on PIN_D5 (VCC/PWM)

unsigned int pump_control = 880;		// PUMP_CONTROL (RAW_POT)		// PUMP_CONTROL - raw pot reading for duty cycle calculation

unsigned int duty_cycle_per = 100;		// DUTY_CYCLE_PER

unsigned int vcc_pump = 0;			// VCC_PUMP				// stores VCC reading of PUMP1 supply

unsigned int pump_rpm_1 = 0;			// PUMP_RPM_1				// stores rpm reading on PIN_D9
unsigned int pump_rpm_2 = 0;			// PUMP_RPM_2				// stores rpm reading on PIN_D11
unsigned int psu_rpm = 0;			// PSU_RPM				// stores rpm reading on PIN_D13

unsigned int pump_flow = 0;			// PUMP_FLOW				// stores current flow rate (in LPM) on PIN_D12 (multiplied by 100)							

unsigned int temp_AN1 = 0;			// TEMP_AN1				// stores TEMP_AN1 readings (PIN_A0) 
unsigned int temp_AN2 = 0;			// TEMP_AN2				// stores TEMP_AN2 readings (PIN_A1)

unsigned int top_temp_AN = 550;			// TOP_TEMP_AN				// stores the current top temperature between temp_AN1 & temp_AN_2

unsigned int vcc_IC = 0;			// VCC_IC				// stores VCC reading of IC supply
unsigned int temp_IC = 0;			// TEMP_IC				// stores temperature reading of IC (alarm watch)
unsigned int ram_IC = 0;			// RAM_IC				// stores IC free ram 

boolean serial_open = false;								// stores state of serial port
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
void loop() {

	if ((got_data) && (!DEBUG_MODE)) send_Data_Processing();

 	short_update_tock = micros();							// current time reference for short update function

	long_update_tock = micros();							// current time reference for long update function

	currentStartupCount = millis();							// current time reference for startup function


	if ((short_update_tock - short_update_tick) >= SHORT_UPDATE_INTERVAL) {		// update function preformed every 0.333334 secondS

		short_update_tick = short_update_tock;					// stores current time reference for next update

		system_status = update_System_Status();

		update_Duty_Cycle();							// updates of TIMER1 & TIMER2 duty cycles

		if ((!DEBUG_MODE) && (serial_open)) PC_Short_Processing_Print();	// prints updated data to processing application
	}


	if ((long_update_tock - long_update_tick) >= LONG_UPDATE_INTERVAL) {		// update function preformed every 1.555556 secondS

		long_update_tick = long_update_tock;					// stores current time reference for next update

		vcc_IC = update_Vcc_IC(); 						// reads vcc_IC

		freq_VCC = read_Frequency(PIN_D3);					// calculates pwm frequency on PIN_D3

		freq_PWM = read_Frequency(PIN_D10);					// calculates pwm frequency on PIN_D10

		vcc_pump = read_VCC_Pump(PIN_A3);					// reads VCC output to PUMP1

		pump_rpm_1 = read_RPM(PIN_D9);						// updates rpm reading on PIN_D9

		pump_rpm_2 = read_RPM(PIN_D11);						// updates rpm reading on PIN_D11

		temp_AN1 = update_Temp_AN(PIN_A0);		// TEMP_AN1		// reads analog temperature sensor on PIN_A0

		psu_rpm = read_RPM(PIN_D13);						// updates rpm reading on PIN_D13

		pump_flow = read_Flow(PIN_D12);						// updates flow meter reading on PIN_D12 (multiplied by 100)

		temp_AN2 = update_Temp_AN(PIN_A1);		// TEMP_AN2		// reads analog temperature sensor on PIN_A1

		top_temp_AN = update_Top_Temp_AN();		// TEMP_AN_TOP

		temp_IC = update_Temp_IC();						// reads temp_IC

		ram_IC = update_Ram_IC();						// reads ram_IC

		temp_OW_1 = read_OW_Temp(OW_DEVICE_1);		// TEMP_OW_1

		if (temp_OW_multiple) update_OW_Temp();		// TEMP_OW		// updates reading of One-Wire temperature sensors if available

		if (temp_I2C_present) update_I2C_Temp();	// TEMP_I2C		// updates reading of I2C temeprature sensors if available

		if (!DEBUG_MODE) {					// PC_MODE

			if (serial_open) PC_Long_Processing_Print();			// prints updated data to processing application
			else check_Serial();

		} else {						// DEBUG_MODE

			if (serial_open) print_Long_Update();				// preforms debugging serial print function
			else check_Serial();
		}
	}
}


ISR(TIMER1_OVF_vect) {									// TIMER1 ISR (pwm frequency counter)
  	ovf1++;										// counts the number of TIMER1 overflows
}

ISR(TIMER2_OVF_vect) {									// TIMER2 ISR (pwm frequency counter)
  	ovf2++;										// counts the number of TIMER2 overflows
}


void burpCount_D9() {									// ISR for interrupt triggers on PIN_D9
  	currentBurp_D9++;
}

void burpCount_D11() {									// ISR for interrupt triggers on PIN_D11
  	currentBurp_D11++;
}

void burpCount_D13() {									// ISR for interrupt triggers on PIN_D13
  	currentBurp_D13++;
}

void burpCount_D12() {									// ISR for interrupt triggers on PIN_D12
  	currentBurp_D12++;
}


void receive_Call (int numBytes) {

	if (numBytes == PC_DATA_IN_COUNT) {
		for (int i = 0; i < numBytes; i++) {
			data_in[i] = Wire.read();
		}
		got_data = true;
	}
}



void request_Call() {	

	Wire.write(PC_PING);
}


unsigned int read_Frequency (const byte pin) {

	volatile unsigned long current_freq;		    	       			// stores total overflow count
	cli();										// disables global interrupts
		switch (pin) {
			case (PIN_D3): current_freq = ovf2; ovf2 = 0; break;		// stores number of TIMER2 overflows & resets Timer2 overflow counter to zero
			case (PIN_D10): current_freq = ovf1; ovf1 = 0; break;		// stores number of TIMER1 overflows & resets Timer1 overflow counter to zero
		}
     	sei();										// enables global interrupts
        current_freq = round(current_freq / LONG_UPDATE_DIVISOR);
	return current_freq;	                                            		// returns new frequency value
}


void update_Duty_Cycle() {

	static unsigned int previous_pump_control;
	static unsigned int delta_pump_control;

	system_control_1 = !(bitRead(PIND, 6));			// OVD_ON/OVD_OFF					// digitalRead(PIN_D6) (0 => OVD_OFF; 1 => OVD_ON)

	system_control_2 = bitRead(PIND, 7);			// MAN/AUTO						// digitalRead(PIN_D7) (0 => MAN; 1 => AUTO)

	system_mode = bitRead(PIND, 5);				// VCC/PWM						// digitalRead(PIN_D5) (0 => VCC; 1 => PWM)

	if ((currentStartupCount >= KICKSTART_INTERVAL) && (!system_control_1)) { 	// OVD_OFF			// SYSTEM_CONTROL_1 => OVD_OFF

		if (bitRead(PINB, 0)) PORTB &= ~(1 << PORTB0);				// OVD_LED_OFF			// turns off SYSTEM_MODE_LED (PIN_D8)

		if (!system_control_2) {			// MANUAL						// SYSTEM_CONTROL => MANUAL

			pump_control = read_ADC(ADC_A2);								// reads pot on PIN_A2 for duty cycle calculation
 
          		if (pump_control < 40) pump_control = 40;

           		if (pump_control > 880) pump_control = 880;

			delta_pump_control = abs(pump_control - previous_pump_control);

			if ((delta_pump_control >= 25) || (pump_control < 65) || (pump_control > 850)) previous_pump_control = pump_control;
                        else pump_control =  previous_pump_control;
				
			if (!system_mode) {			// MANUAL_VCC						// PUMP_MODE_VCC (TIMER2)
			
				current_duty_cycle = map_Float(float(pump_control), 40.0, 880.0, 28.0, 78.0);		// calculates duty cycle on PIN_D3 (minimum duty set to 25%)

				if ((ocr2b_data != current_duty_cycle) || (ocr1b_data != 638)) {
					cli(); 										// disables global interrupts
						if (OCR2B != current_duty_cycle) OCR2B = current_duty_cycle;		// sets TIMER2 duty cycle to to new value
						if (OCR1B != 638) OCR1B = 638;						// sets TIMER1 duty cycle to maximum value
					sei();										// enables global interrupts
					ocr2b_data = current_duty_cycle;						// stores value of OCR2B register
					ocr1b_data = 638;								// stores value of OCR1B register
				}
				duty_cycle_per = map_Float(float(current_duty_cycle), 28.0, 78.0, 36.0, 100.0);

			} else {				// MANUAL_PWM						// PUMP_MODE_PWM (TIMER1)

				current_duty_cycle = map_Float(float(pump_control), 40.0, 880.0, 230.0, 638.0);		// calculates duty cycle on PIN_D10 (minimum duty set to 25%)

				if ((ocr1b_data != current_duty_cycle) || (ocr2b_data != 78)) {
					cli(); 										// disables global interrupts
						if (OCR1B != current_duty_cycle) OCR1B = current_duty_cycle;		// sets TIMER1 duty cycle to to new value
						if (OCR2B != 78) OCR2B = 78;						// sets TIMER2 duty cycle to maximum value
					sei();										// enables global interrupts
					ocr1b_data = current_duty_cycle;						// stores value of OCR1B register
					ocr2b_data = 78;								// stores value of OCR2B register
				}
				duty_cycle_per = map_Float(float(current_duty_cycle), 230.0, 638.0, 36.0, 100.0);
			}

		} else {					// AUTO							// SYSTEM_CONTROL => AUTO

			if (!system_mode) {			// AUTO_VCC						// PUMP_MODE_VCC (TIMER2)

				current_duty_cycle = map_Float(float(top_temp_AN), 200.0, 550.0, 28.0, 78.0);

				if ((ocr2b_data != current_duty_cycle) || (ocr1b_data != 638)) {
					cli(); 										// disables global interrupts
						if (OCR2B != current_duty_cycle) OCR2B = current_duty_cycle;		// sets TIMER2 duty cycle to to new value
						if (OCR1B != 638) OCR1B = 638;						// sets TIMER1 duty cycle to maximum value
					sei();										// enables global interrupts
					ocr2b_data = current_duty_cycle;						// stores value of OCR2B register
					ocr1b_data = 638;								// stores value of OCR1B register
				}
				duty_cycle_per = map_Float(float(current_duty_cycle), 28.0, 78.0, 36.0, 100.0);

			} else {				// AUTO_PWM						// PUMP_MODE_PWM (TIMER1)			

				current_duty_cycle = map_Float(float(top_temp_AN), 200.0, 550.0, 230.0, 638.0);

				if ((ocr1b_data != current_duty_cycle) || (ocr2b_data != 78)) {
					cli(); 										// disables global interrupts
						if (OCR1B != current_duty_cycle) OCR1B = current_duty_cycle;		// sets TIMER1 duty cycle to to new value
						if (OCR2B != 78) OCR2B = 78;						// sets TIMER2 duty cycle to maximum value
					sei();										// enables global interrupts
					ocr1b_data = current_duty_cycle;						// stores value of OCR1B register
					ocr2b_data = 78;								// stores value of OCR2B register
				}
				duty_cycle_per = map_Float(float(current_duty_cycle), 230.0, 638.0, 36.0, 100.0);
			}
		}

	} else {									// OVD_ON			// SYSTEM_CONTROL_1 => OVERDRIVE_ON

		if (!(bitRead(PINB, 0))) PORTB |= (1 << PORTB0);			// OVD_LED_ON			// turns on SYSTEM_CONTROL_LED (PIN_D8)

		system_control_1 = true;     			 							// changes system_control_1 to indicate OVD_ON
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

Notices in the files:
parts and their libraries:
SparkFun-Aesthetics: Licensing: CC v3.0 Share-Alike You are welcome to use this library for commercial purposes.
